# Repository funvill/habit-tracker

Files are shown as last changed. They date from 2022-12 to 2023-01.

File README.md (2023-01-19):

# Every DayCalendar - Single Month board - KiCad

A single month habit tracker inspired by [Simone Giertz “The Every Day Calendar”](https://www.kickstarter.com/projects/simonegiertz/the-every-day-calendar). Allows for tracking of stats for multiple activities throughout the year. On each day, click the buttons for the activities that you have accomplished and the corresponding date on the calendar will illuminate with RGB LEDs.

- Months will progress automatically.
- Several different "modes"
- Physical buttons with leads to be able to expand on the board out to a frame.
- Ability to connect the boards together

Uses a ESP32 to connect to the internet and backup the data from the boards.

Fabricated using JLPCB SMD placement services. Fully automated manufacturing.

More information about this project can be found on my blog [project page](https://blog.abluestar.com/projects/2022-monthly-habit-tracker/)

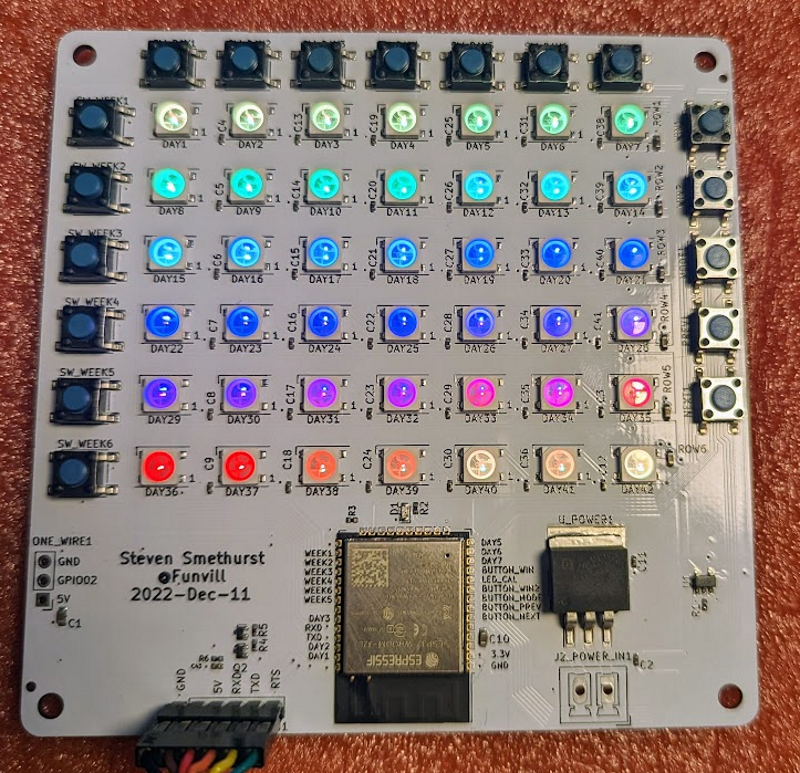
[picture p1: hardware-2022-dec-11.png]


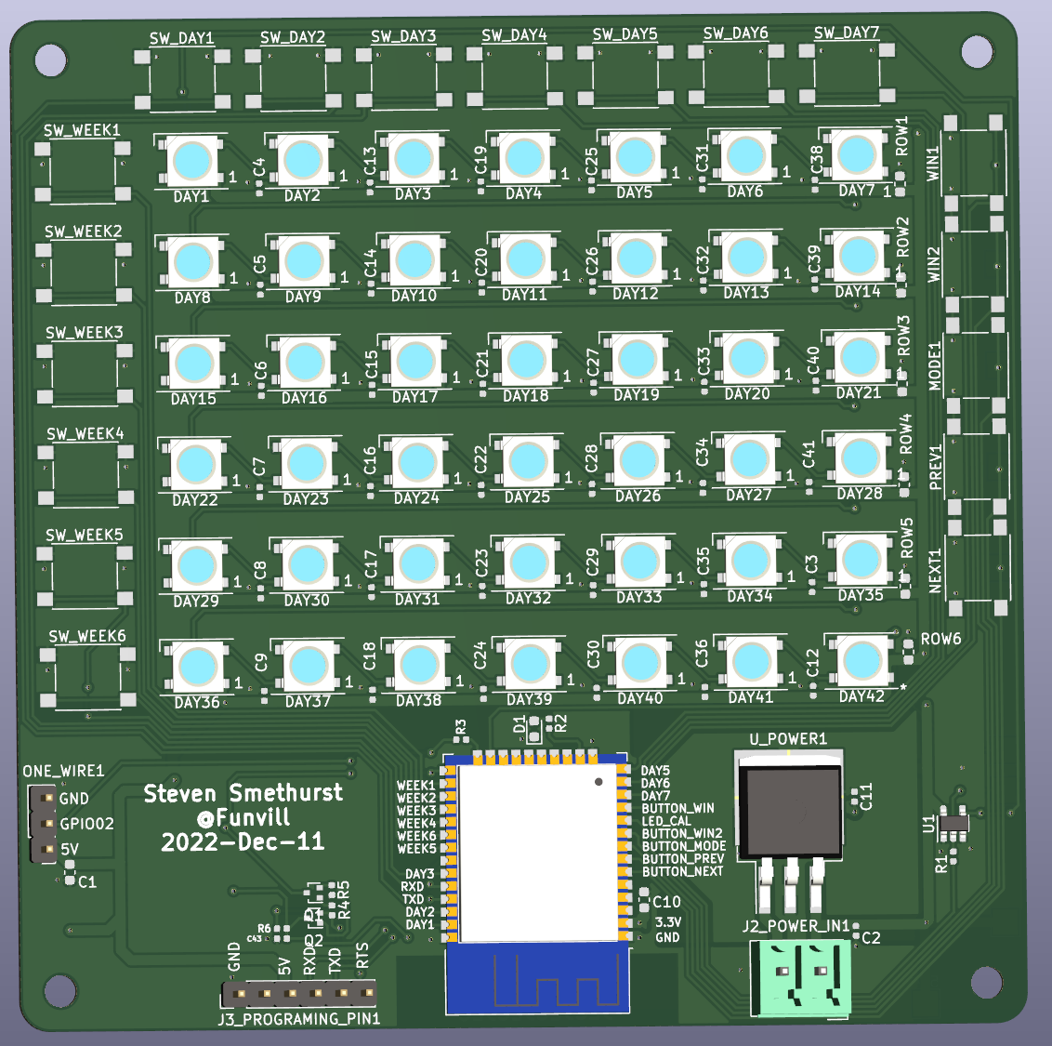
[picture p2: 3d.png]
3D


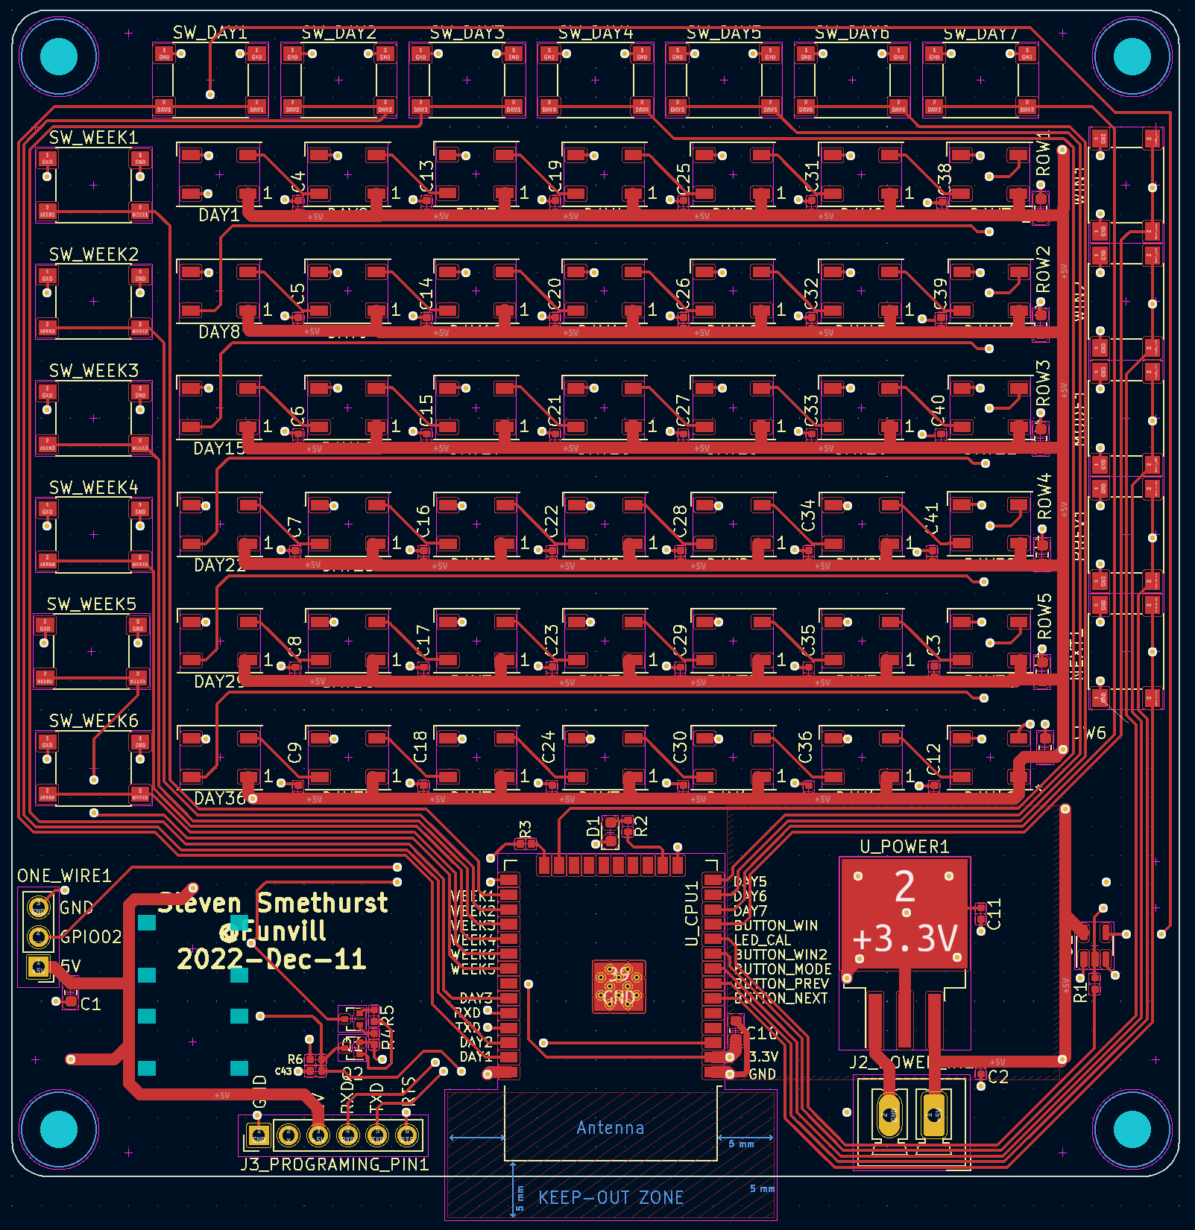
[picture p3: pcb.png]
PCB


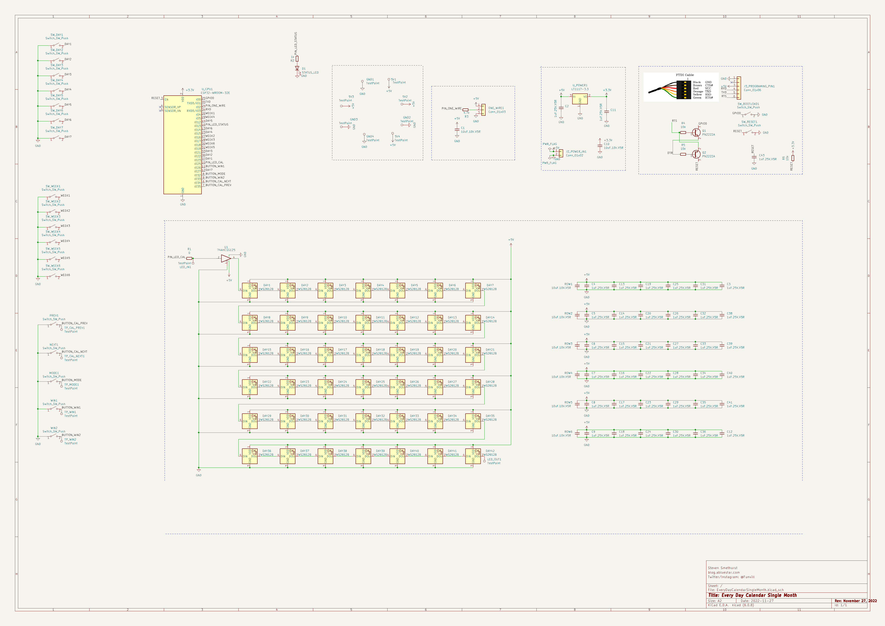
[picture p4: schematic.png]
Schematic


See [changelog](changelog.md) for full list of changes

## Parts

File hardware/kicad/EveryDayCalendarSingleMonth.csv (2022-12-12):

Comment | Designator | Footprint | LCSC
TestPoint | GND1,LED_IN1,LED_OUT1,TP_CAL_NEXT1,TP_CAL_PREV1,TP_MODE1,TP_WIN1,GND2,TP_WIN2,GND3,GND4,5V1,5V2,5V3,5V4 | TestPoint:TestPoint_Pad_2.5x2.5mm
10uF,10V,X5R | C1,ROW1,ROW2,ROW3,ROW4,ROW5,ROW6,C10 | tom-passives:C_0603_1608Metric | C19702
1uF,25V,X5R | C2,C3,C4,C5,C6,C7,C8,C9,C11,C12,C13,C14,C15,C16,C17,C18,C19,C20,C21,C22,C23,C24,C25,C26,C27,C28,C29,C30,C31,C32,C33,C34,C35,C36,C38,C39,C40,C41,C43 | tom-passives:C_0402_1005Metric | C52923
STATUS_LED | D1 | tom-opto:LED_0603_1608Metric | C2286
WS2812B | DAY1,DAY2,DAY3,DAY4,DAY5,DAY6,DAY7,DAY8,DAY9,DAY10,DAY11,DAY12,DAY13,DAY14,DAY15,DAY16,DAY17,DAY18,DAY19,DAY20,DAY21,DAY22,DAY23,DAY24,DAY25,DAY26,DAY27,DAY28,DAY29,DAY30,DAY31,DAY32,DAY33,DAY34,DAY35,DAY36,DAY37,DAY38,DAY39,DAY40,DAY41,DAY42 | LED_SMD:LED_WS2812B_PLCC4_5.0x5.0mm_P3.2mm | C2843785
Conn_01x02 | J2_POWER_IN1 | Connector_Phoenix_MC:PhoenixContact_MCV_1,5_2-G-3.81_1x02_P3.81mm_Vertical
Conn_01x06 | J3_PROGRAMING_PIN1 | Connector_PinHeader_2.54mm:PinHeader_1x06_P2.54mm_Vertical
Switch_SW_Push | MODE1,NEXT1,PREV1,SW_BOOTLOAD1,SW_DAY1,SW_RESET1,SW_WEEK1,WIN1,SW_DAY2,SW_WEEK2,WIN2,SW_DAY3,SW_WEEK3,SW_DAY4,SW_WEEK4,SW_DAY5,SW_WEEK5,SW_DAY6,SW_WEEK6,SW_DAY7 | calendar:SW_Push_1P1T_NO_6x6mm_H9.5mm | C221880
Conn_01x03 | ONE_WIRE1 | Connector_PinHeader_2.54mm:PinHeader_1x03_P2.54mm_Vertical
PN2222A | Q1,Q2 | Package_TO_SOT_SMD:SOT-416 | C242260
0 | R1 | tom-passives:R_0402_1005Metric | C17168
1k | R2 | tom-passives:R_0402_1005Metric | C11702
4.7k | R3 | tom-passives:R_0402_1005Metric | C25900
10k | R4,R5,R6 | tom-passives:R_0402_1005Metric | C25744
74AHC1G125 | U1 | calendar:SOT-23-5 | C23654
ESP32-WROOM-32E | U_CPU1 | RF_Module:ESP32-WROOM-32 | C701342
LT1117-3.3 | U_POWER1 | Package_TO_SOT_SMD:TO-263-3_TabPin2 | C498315

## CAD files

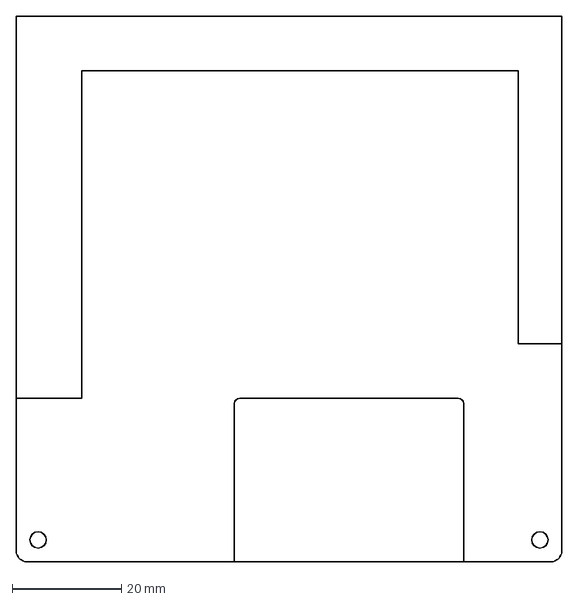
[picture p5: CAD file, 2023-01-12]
mounting/1month_top_plate.dxf
100.0 x 100.0 mm

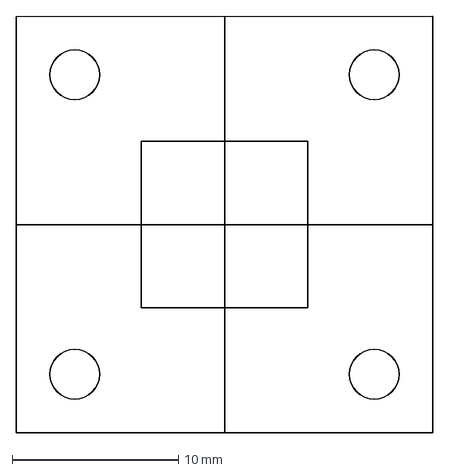
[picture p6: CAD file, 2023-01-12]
mounting/seperator.dxf
25.0 x 25.0 mm

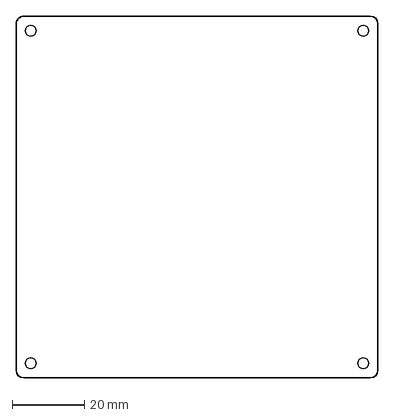
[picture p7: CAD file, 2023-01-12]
mounting/1month_bottom_plate.dxf
100.0 x 100.0 mm

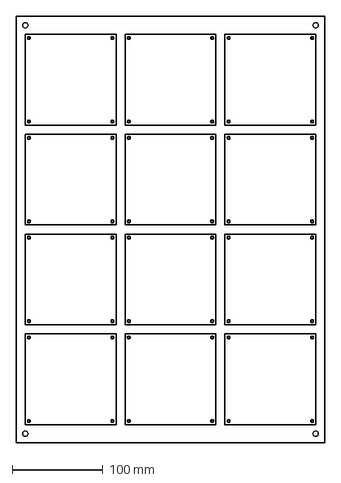
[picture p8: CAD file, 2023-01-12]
mounting/12MonthCalendar_backing.dxf
340.0 x 470.0 mm

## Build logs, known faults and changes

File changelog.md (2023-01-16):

# Change log

## 2023-Jan-08 (build 8)

- Fixed isssue where mode was not being saved between power cycles
## 2023-Jan-08 (build 7)

- Fixed bug where year was read from settings as a signed instead of unsigned short
- Removed github actions that are not needed

## 2023-Jan-08 (build 6)

- Save the month, year, and mode to eeprom on change
- Randomized seed on startup based on wifi noise

## 2023-Jan-08 (build 3-5)

- Added ability to update via Github

## 2023-Jan-03 (build 2)

- Added a fades pixel animation
- Moved modes to their own files
- Added reset wifi command

## 2022-Dec-29 (build 1)

- Intial version
- Added mode Calendar
  - Set current date objectives
  - Button to go to Next and Previouse month/year
  - Requires internet connection for NTP server (time)
- Captive portal on start up for entering Wifi settings
- Web server
  - Current state
  - Reset database
  - download database
- Reading/Writing to EEPROM
  - settings and database
- Added mode binary clock

## 2022-Dec-26

- Hardware recived

## 2022-Dec-11

- Hardware design done
- Submitted the PCBs to the fabrication servive (JLPCB) for manufacturing.

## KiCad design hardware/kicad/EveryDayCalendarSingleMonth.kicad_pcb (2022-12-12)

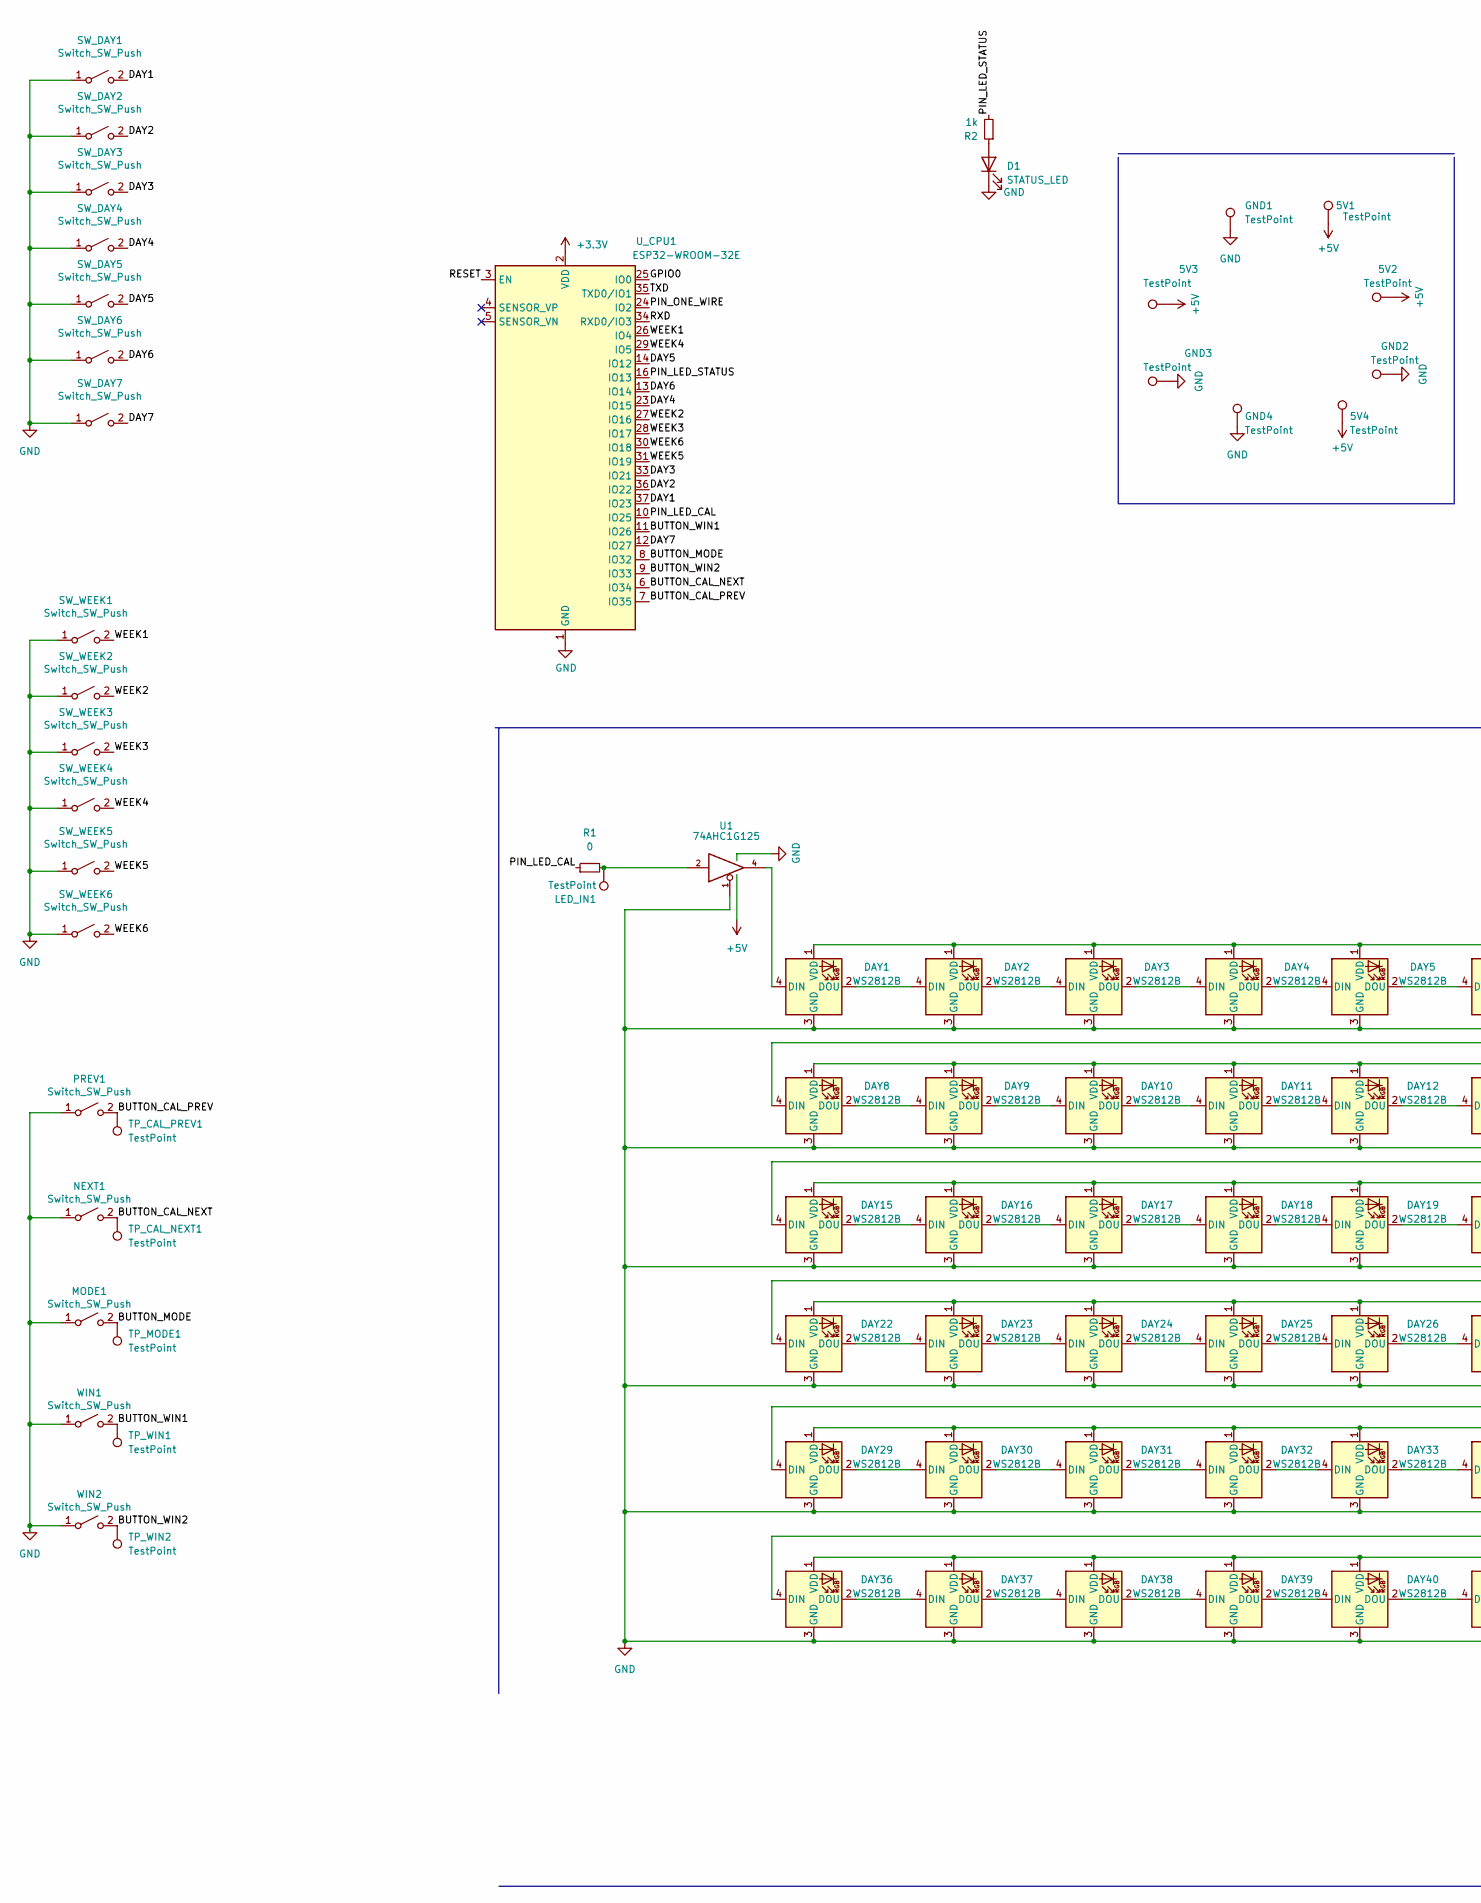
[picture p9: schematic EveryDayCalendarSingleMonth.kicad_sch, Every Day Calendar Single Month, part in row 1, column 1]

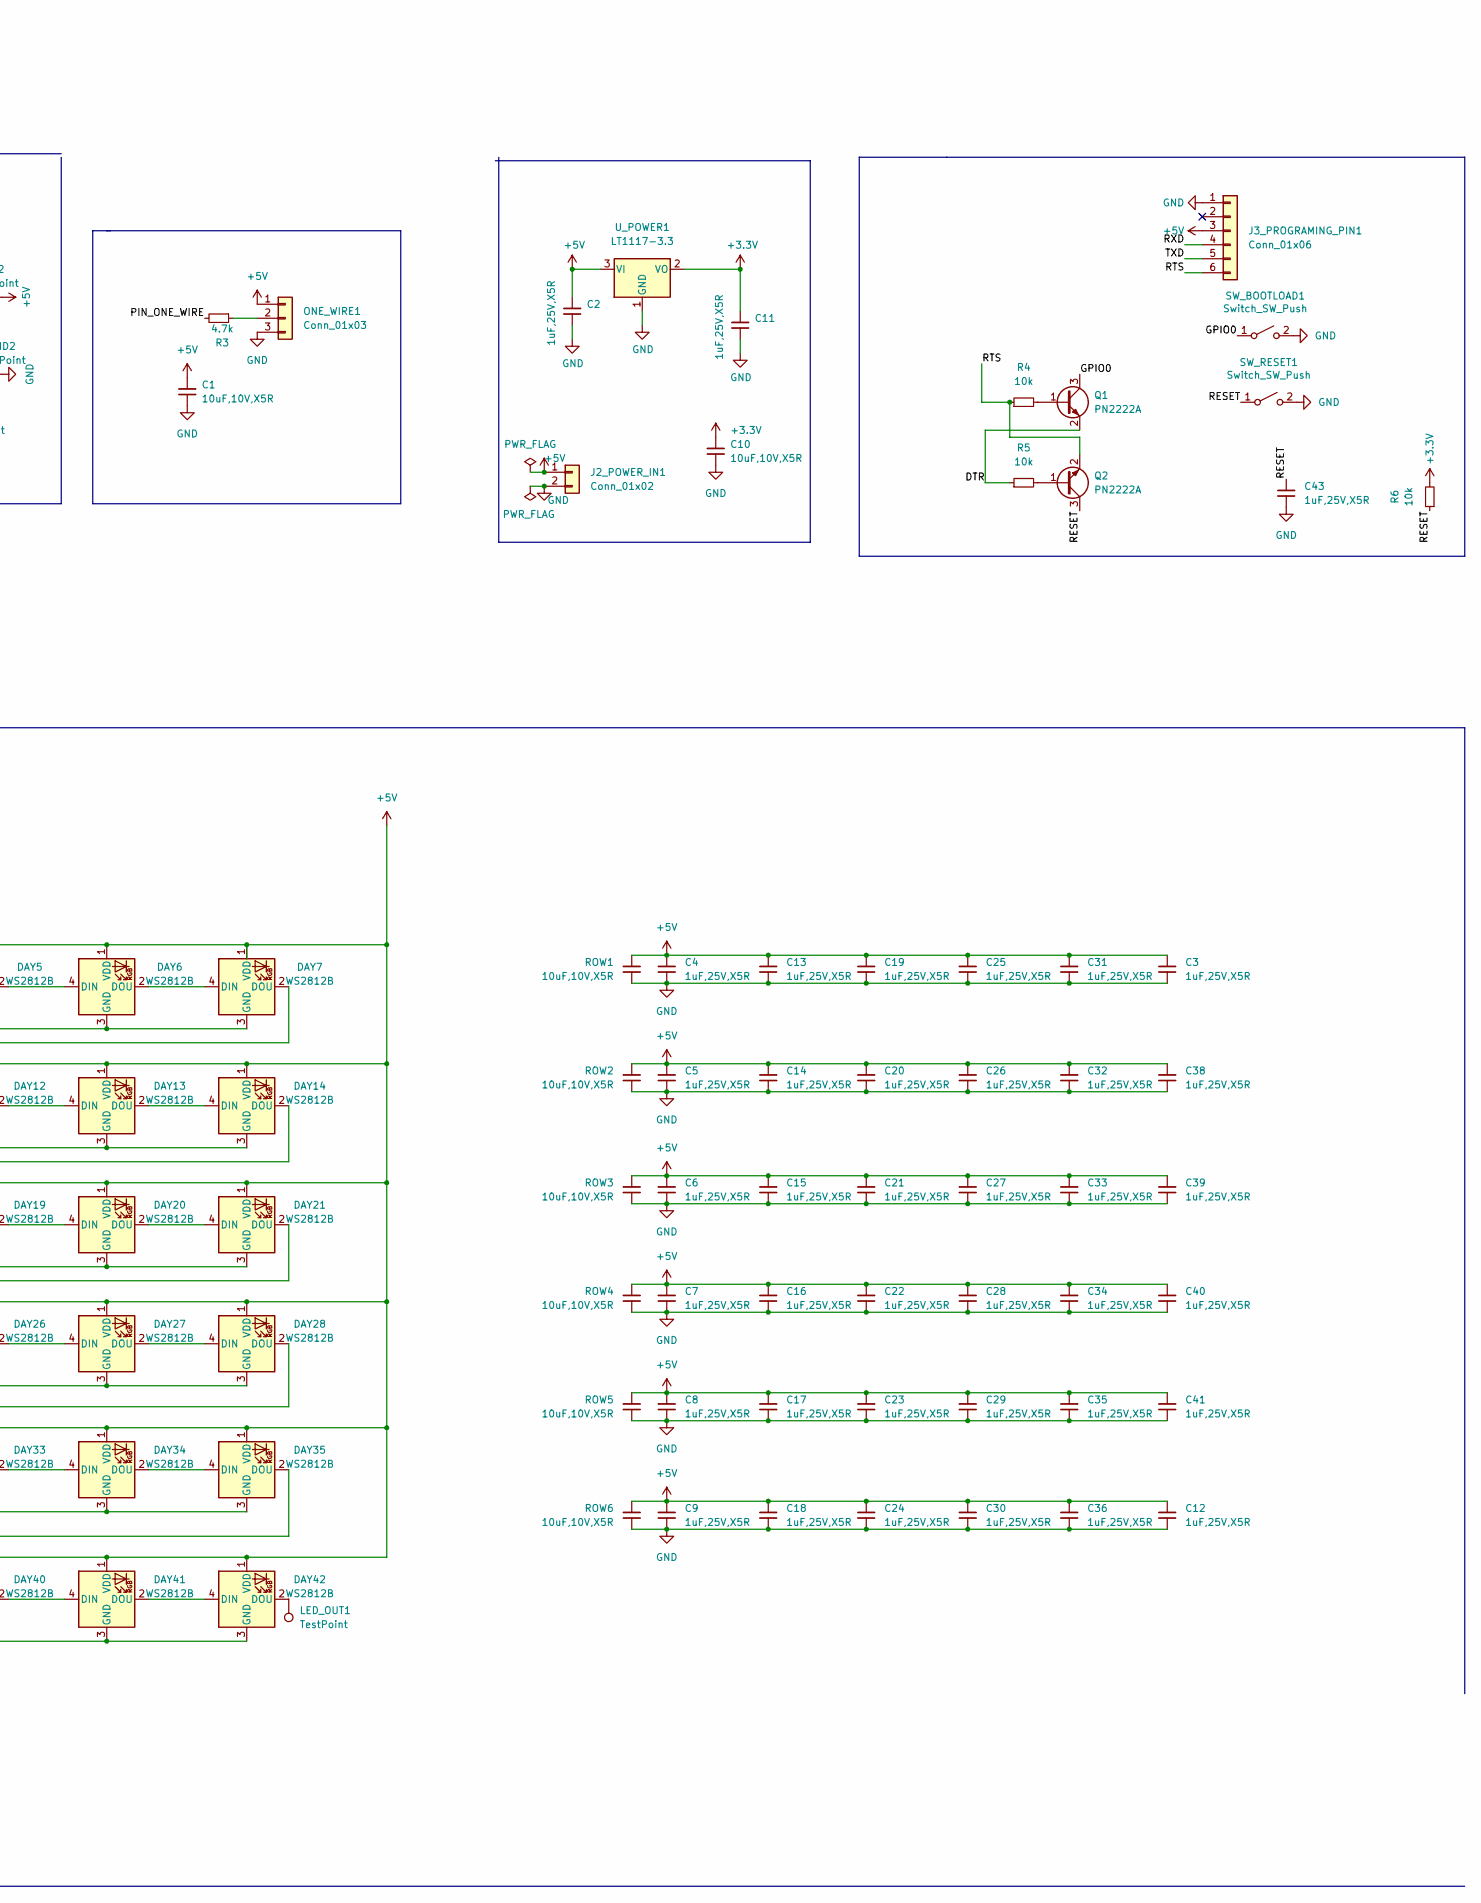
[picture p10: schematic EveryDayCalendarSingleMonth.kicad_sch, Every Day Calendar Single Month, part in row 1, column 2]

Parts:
5V1, 5V2, 5V3, 5V4: TestPoint; TestPoint_Pad_2.5x2.5mm
C1, C10: 10uF,10V,X5R; C_0603_1608Metric; MFGPN CL10A106KP8NNNC; LCSC C19702
C2, C3, C4, C5, C6, C7, C8, C9, C11, C12, C13, C14, C15, C16, C17, C18, C19, C20, C21, C22, C23, C24, C25, C26, C27, C28, C29, C30, C31, C32, C33, C34, C35, C36, C38, C39, C40, C41, C43: 1uF,25V,X5R; C_0402_1005Metric; MFGPN CL05A105KA5NQNC; LCSC C52923
D1: STATUS_LED; LED_0603_1608Metric; LCSC C2286
DAY1, DAY2, DAY3, DAY4, DAY5, DAY6, DAY7, DAY8, DAY9, DAY10, DAY11, DAY12, DAY13, DAY14, DAY15, DAY16, DAY17, DAY18, DAY19, DAY20, DAY21, DAY22, DAY23, DAY24, DAY25, DAY26, DAY27, DAY28, DAY29, DAY30, DAY31, DAY32, DAY33, DAY34, DAY35, DAY36, DAY37, DAY38, DAY39, DAY40, DAY41, DAY42: WS2812B; LED_WS2812B_PLCC4_5.0x5.0mm_P3.2mm; LCSC C2843785
GND1, GND2, GND3, GND4: TestPoint; TestPoint_Pad_2.5x2.5mm
J2_POWER_IN1: Conn_01x02; PhoenixContact_MCV_1,5_2-G-3.81_1x02_P3.81mm_Vertical
J3_PROGRAMING_PIN1: Conn_01x06; PinHeader_1x06_P2.54mm_Vertical
LED_IN1: TestPoint; TestPoint_Pad_2.5x2.5mm
LED_OUT1: TestPoint; TestPoint_Pad_2.5x2.5mm
MODE1: Switch_SW_Push; SW_Push_1P1T_NO_6x6mm_H9.5mm; LCSC C221880
NEXT1: Switch_SW_Push; SW_Push_1P1T_NO_6x6mm_H9.5mm; LCSC C221880
ONE_WIRE1: Conn_01x03; PinHeader_1x03_P2.54mm_Vertical
PREV1: Switch_SW_Push; SW_Push_1P1T_NO_6x6mm_H9.5mm; LCSC C221880
Q1, Q2: PN2222A; SOT-416; LCSC C242260
R1: 0; R_0402_1005Metric; MFGPN 0402WGF0000TCE; LCSC C17168
R2: 1k; R_0402_1005Metric; MFGPN 0402WGF1001TCE; LCSC C11702
R3: 4.7k; R_0402_1005Metric; MFGPN 0402WGF4701TCE; LCSC C25900
R4, R5, R6: 10k; R_0402_1005Metric; MFGPN 0402WGF1002TCE; LCSC C25744
ROW1, ROW2, ROW3, ROW4, ROW5, ROW6: 10uF,10V,X5R; C_0603_1608Metric; MFGPN CL10A106KP8NNNC; LCSC C19702
SW_BOOTLOAD1: Switch_SW_Push; SW_Push_1P1T_NO_6x6mm_H9.5mm; LCSC DNP
SW_DAY1, SW_DAY2, SW_DAY3, SW_DAY4, SW_DAY5, SW_DAY6, SW_DAY7: Switch_SW_Push; SW_Push_1P1T_NO_6x6mm_H9.5mm; LCSC C221880
SW_RESET1: Switch_SW_Push; SW_Push_1P1T_NO_6x6mm_H9.5mm; LCSC DNP
SW_WEEK1, SW_WEEK2, SW_WEEK3, SW_WEEK4, SW_WEEK5, SW_WEEK6: Switch_SW_Push; SW_Push_1P1T_NO_6x6mm_H9.5mm; LCSC C221880
TP_CAL_NEXT1: TestPoint; TestPoint_Pad_2.5x2.5mm
TP_CAL_PREV1: TestPoint; TestPoint_Pad_2.5x2.5mm
TP_MODE1: TestPoint; TestPoint_Pad_2.5x2.5mm
TP_WIN1, TP_WIN2: TestPoint; TestPoint_Pad_2.5x2.5mm
U1: 74AHC1G125; SOT-23-5; LCSC C23654
U_CPU1: ESP32-WROOM-32E; ESP32-WROOM-32; LCSC C701342
U_POWER1: LT1117-3.3; TO-263-3_TabPin2; LCSC C498315
WIN1, WIN2: Switch_SW_Push; SW_Push_1P1T_NO_6x6mm_H9.5mm; LCSC C221880

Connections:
+3.3V: C10.1, C11.1, R6.2, U_CPU1.2 (VDD), U_POWER1.2 (VO)
+5V: 5V1.1, 5V2.1, 5V3.1, 5V4.1, C1.1, C2.1, C3.1, C4.1, C5.1, C6.1, C7.1, C8.1, C9.1, C12.1, C13.1, C14.1, C15.1, C16.1, C17.1, C18.1, C19.1, C20.1, C21.1, C22.1, C23.1, C24.1, C25.1, C26.1, C27.1, C28.1, C29.1, C30.1, C31.1, C32.1, C33.1, C34.1, C35.1, C36.1, C38.1, C39.1, C40.1, C41.1, DAY1.1 (VDD), DAY2.1 (VDD), DAY3.1 (VDD), DAY4.1 (VDD), DAY5.1 (VDD), DAY6.1 (VDD), DAY7.1 (VDD), DAY8.1 (VDD), DAY9.1 (VDD), DAY10.1 (VDD), DAY11.1 (VDD), DAY12.1 (VDD), DAY13.1 (VDD), DAY14.1 (VDD), DAY15.1 (VDD), DAY16.1 (VDD), DAY17.1 (VDD), DAY18.1 (VDD), DAY19.1 (VDD), DAY20.1 (VDD), DAY21.1 (VDD), DAY22.1 (VDD), DAY23.1 (VDD), DAY24.1 (VDD), DAY25.1 (VDD), DAY26.1 (VDD), DAY27.1 (VDD), DAY28.1 (VDD), DAY29.1 (VDD), DAY30.1 (VDD), DAY31.1 (VDD), DAY32.1 (VDD), DAY33.1 (VDD), DAY34.1 (VDD), DAY35.1 (VDD), DAY36.1 (VDD), DAY37.1 (VDD), DAY38.1 (VDD), DAY39.1 (VDD), DAY40.1 (VDD), DAY41.1 (VDD), DAY42.1 (VDD), J2_POWER_IN1.1, J3_PROGRAMING_PIN1.3, ONE_WIRE1.1, ROW1.2, ROW2.2, ROW3.2, ROW4.2, ROW5.2, ROW6.2, U1.5 (VCC), U_POWER1.3 (VI)
/BUTTON_CAL_NEXT: NEXT1.2 (B), TP_CAL_NEXT1.1, U_CPU1.6 (IO34)
/BUTTON_CAL_PREV: PREV1.2 (B), TP_CAL_PREV1.1, U_CPU1.7 (IO35)
/BUTTON_MODE: MODE1.2 (B), TP_MODE1.1, U_CPU1.8 (IO32)
/BUTTON_WIN1: TP_WIN1.1, U_CPU1.11 (IO26), WIN1.2 (B)
/BUTTON_WIN2: TP_WIN2.1, U_CPU1.9 (IO33), WIN2.2 (B)
/DAY1: SW_DAY1.2 (B), U_CPU1.37 (IO23)
/DAY2: SW_DAY2.2 (B), U_CPU1.36 (IO22)
/DAY3: SW_DAY3.2 (B), U_CPU1.33 (IO21)
/DAY4: SW_DAY4.2 (B), U_CPU1.23 (IO15)
/DAY5: SW_DAY5.2 (B), U_CPU1.14 (IO12)
/DAY6: SW_DAY6.2 (B), U_CPU1.13 (IO14)
/DAY7: SW_DAY7.2 (B), U_CPU1.12 (IO27)
/DTR: Q1.2 (E), R5.1
/GPIO0: Q1.3 (C), SW_BOOTLOAD1.1 (A), U_CPU1.25 (IO0)
/PIN_LED_CAL: R1.1, U_CPU1.10 (IO25)
/PIN_LED_STATUS: R2.2, U_CPU1.16 (IO13)
/PIN_ONE_WIRE: R3.2, U_CPU1.24 (IO2)
/RESET: C43.1, Q2.3 (C), R6.1, SW_RESET1.1 (A), U_CPU1.3 (EN)
/RTS: J3_PROGRAMING_PIN1.6, Q2.2 (E), R4.1
/RXD: J3_PROGRAMING_PIN1.4, U_CPU1.34 (RXD0/IO3)
/TXD: J3_PROGRAMING_PIN1.5, U_CPU1.35 (TXD0/IO1)
/WEEK1: SW_WEEK1.2 (B), U_CPU1.26 (IO4)
/WEEK2: SW_WEEK2.2 (B), U_CPU1.27 (IO16)
/WEEK3: SW_WEEK3.2 (B), U_CPU1.28 (IO17)
/WEEK4: SW_WEEK4.2 (B), U_CPU1.29 (IO5)
/WEEK5: SW_WEEK5.2 (B), U_CPU1.31 (IO19)
/WEEK6: SW_WEEK6.2 (B), U_CPU1.30 (IO18)
GND: C1.2, C2.2, C3.2, C4.2, C5.2, C6.2, C7.2, C8.2, C9.2, C10.2, C11.2, C12.2, C13.2, C14.2, C15.2, C16.2, C17.2, C18.2, C19.2, C20.2, C21.2, C22.2, C23.2, C24.2, C25.2, C26.2, C27.2, C28.2, C29.2, C30.2, C31.2, C32.2, C33.2, C34.2, C35.2, C36.2, C38.2, C39.2, C40.2, C41.2, C43.2, D1.1 (K), DAY1.3 (GND), DAY2.3 (GND), DAY3.3 (GND), DAY4.3 (GND), DAY5.3 (GND), DAY6.3 (GND), DAY7.3 (GND), DAY8.3 (GND), DAY9.3 (GND), DAY10.3 (GND), DAY11.3 (GND), DAY12.3 (GND), DAY13.3 (GND), DAY14.3 (GND), DAY15.3 (GND), DAY16.3 (GND), DAY17.3 (GND), DAY18.3 (GND), DAY19.3 (GND), DAY20.3 (GND), DAY21.3 (GND), DAY22.3 (GND), DAY23.3 (GND), DAY24.3 (GND), DAY25.3 (GND), DAY26.3 (GND), DAY27.3 (GND), DAY28.3 (GND), DAY29.3 (GND), DAY30.3 (GND), DAY31.3 (GND), DAY32.3 (GND), DAY33.3 (GND), DAY34.3 (GND), DAY35.3 (GND), DAY36.3 (GND), DAY37.3 (GND), DAY38.3 (GND), DAY39.3 (GND), DAY40.3 (GND), DAY41.3 (GND), DAY42.3 (GND), GND1.1, GND2.1, GND3.1, GND4.1, J2_POWER_IN1.2, J3_PROGRAMING_PIN1.1, MODE1.1 (A), NEXT1.1 (A), ONE_WIRE1.3, PREV1.1 (A), ROW1.1, ROW2.1, ROW3.1, ROW4.1, ROW5.1, ROW6.1, SW_BOOTLOAD1.2 (B), SW_DAY1.1 (A), SW_DAY2.1 (A), SW_DAY3.1 (A), SW_DAY4.1 (A), SW_DAY5.1 (A), SW_DAY6.1 (A), SW_DAY7.1 (A), SW_RESET1.2 (B), SW_WEEK1.1 (A), SW_WEEK2.1 (A), SW_WEEK3.1 (A), SW_WEEK4.1 (A), SW_WEEK5.1 (A), SW_WEEK6.1 (A), U1.1, U1.3 (GND), U_CPU1.1 (GND), U_CPU1.15 (GND), U_CPU1.38 (GND), U_CPU1.39 (GND), U_POWER1.1 (GND), WIN1.1 (A), WIN2.1 (A)
unnamed: D1.2 (A), R2.1
unnamed: DAY1.2 (DOU), DAY2.4 (DIN)
unnamed: DAY1.4 (DIN), U1.4
unnamed: DAY2.2 (DOU), DAY3.4 (DIN)
unnamed: DAY3.2 (DOU), DAY4.4 (DIN)
unnamed: DAY4.2 (DOU), DAY5.4 (DIN)
unnamed: DAY5.2 (DOU), DAY6.4 (DIN)
unnamed: DAY6.2 (DOU), DAY7.4 (DIN)
unnamed: DAY7.2 (DOU), DAY8.4 (DIN)
unnamed: DAY8.2 (DOU), DAY9.4 (DIN)
unnamed: DAY10.2 (DOU), DAY11.4 (DIN)
unnamed: DAY9.2 (DOU), DAY10.4 (DIN)
unnamed: DAY11.2 (DOU), DAY12.4 (DIN)
unnamed: DAY12.2 (DOU), DAY13.4 (DIN)
unnamed: DAY13.2 (DOU), DAY14.4 (DIN)
unnamed: DAY14.2 (DOU), DAY15.4 (DIN)
unnamed: DAY15.2 (DOU), DAY16.4 (DIN)
unnamed: DAY16.2 (DOU), DAY17.4 (DIN)
unnamed: DAY17.2 (DOU), DAY18.4 (DIN)
unnamed: DAY18.2 (DOU), DAY19.4 (DIN)
unnamed: DAY19.2 (DOU), DAY20.4 (DIN)
unnamed: DAY20.2 (DOU), DAY21.4 (DIN)
unnamed: DAY21.2 (DOU), DAY22.4 (DIN)
unnamed: DAY22.2 (DOU), DAY23.4 (DIN)
unnamed: DAY23.2 (DOU), DAY24.4 (DIN)
unnamed: DAY24.2 (DOU), DAY25.4 (DIN)
unnamed: DAY25.2 (DOU), DAY26.4 (DIN)
unnamed: DAY26.2 (DOU), DAY27.4 (DIN)
unnamed: DAY27.2 (DOU), DAY28.4 (DIN)
unnamed: DAY28.2 (DOU), DAY29.4 (DIN)
unnamed: DAY29.2 (DOU), DAY30.4 (DIN)
unnamed: DAY30.2 (DOU), DAY31.4 (DIN)
unnamed: DAY31.2 (DOU), DAY32.4 (DIN)
unnamed: DAY32.2 (DOU), DAY33.4 (DIN)
unnamed: DAY33.2 (DOU), DAY34.4 (DIN)
unnamed: DAY34.2 (DOU), DAY35.4 (DIN)
unnamed: DAY35.2 (DOU), DAY36.4 (DIN)
unnamed: DAY36.2 (DOU), DAY37.4 (DIN)
unnamed: DAY37.2 (DOU), DAY38.4 (DIN)
unnamed: DAY38.2 (DOU), DAY39.4 (DIN)
unnamed: DAY39.2 (DOU), DAY40.4 (DIN)
unnamed: DAY40.2 (DOU), DAY41.4 (DIN)
unnamed: DAY41.2 (DOU), DAY42.4 (DIN)
unnamed: DAY42.2 (DOU), LED_OUT1.1
unnamed: LED_IN1.1, R1.2, U1.2
unnamed: ONE_WIRE1.2, R3.1
unnamed: Q1.1 (B), R4.2
unnamed: Q2.1 (B), R5.2

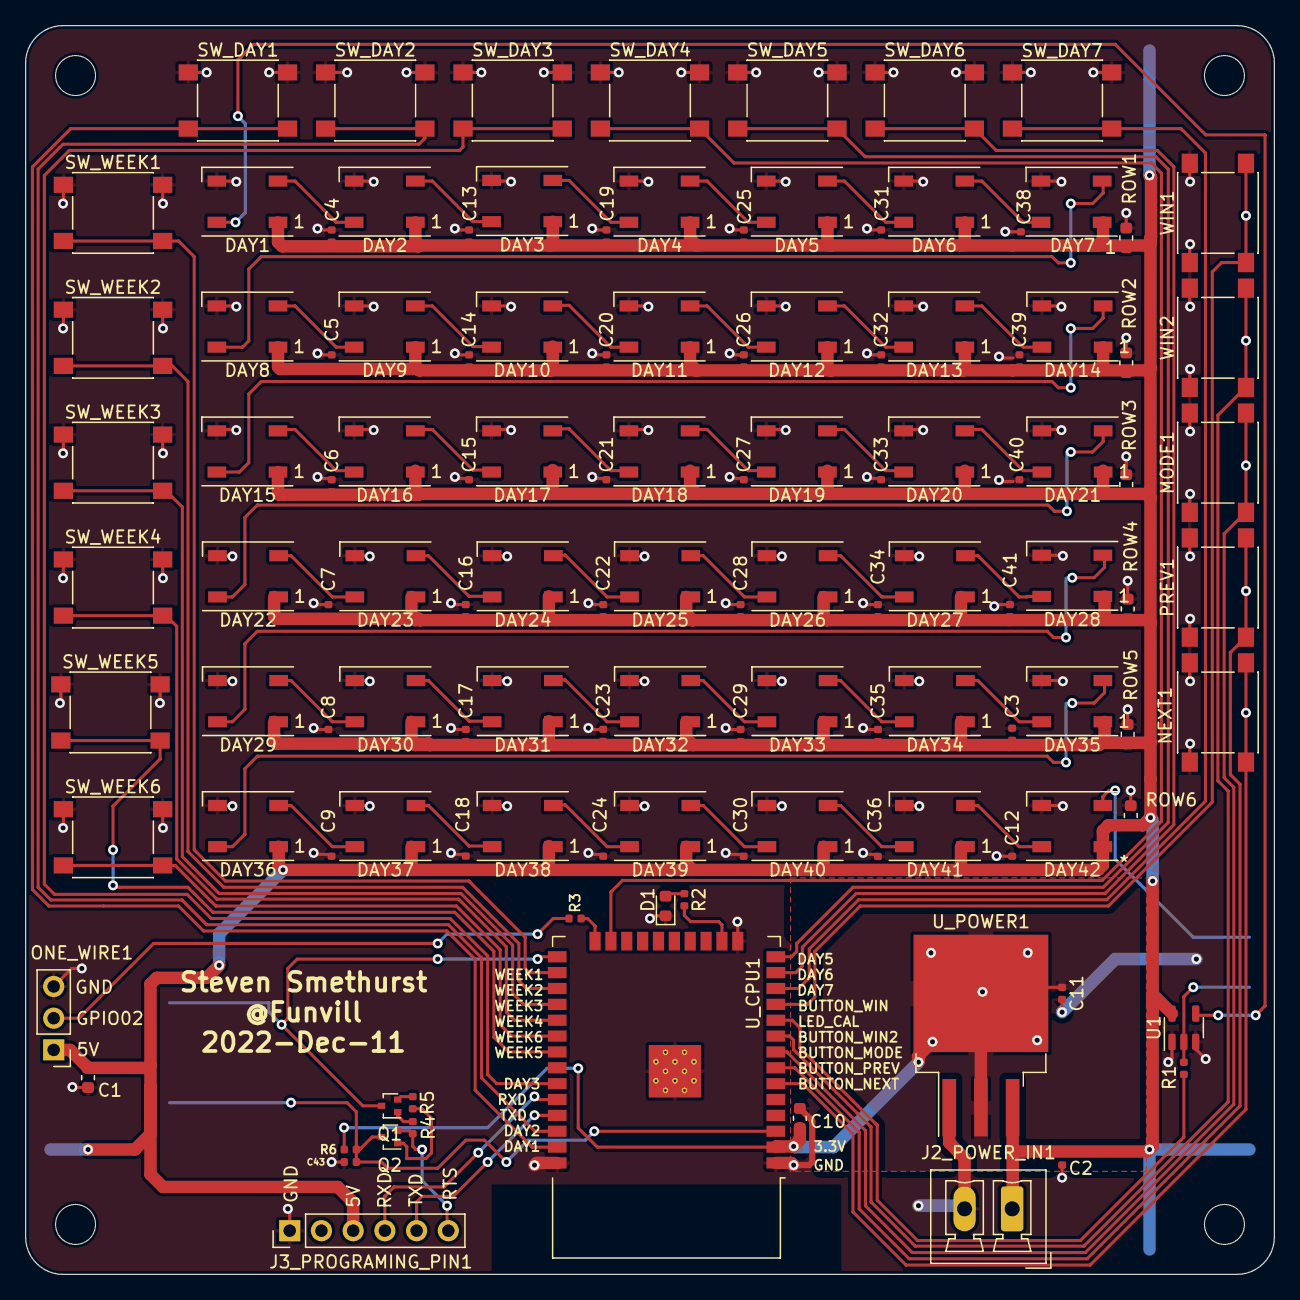
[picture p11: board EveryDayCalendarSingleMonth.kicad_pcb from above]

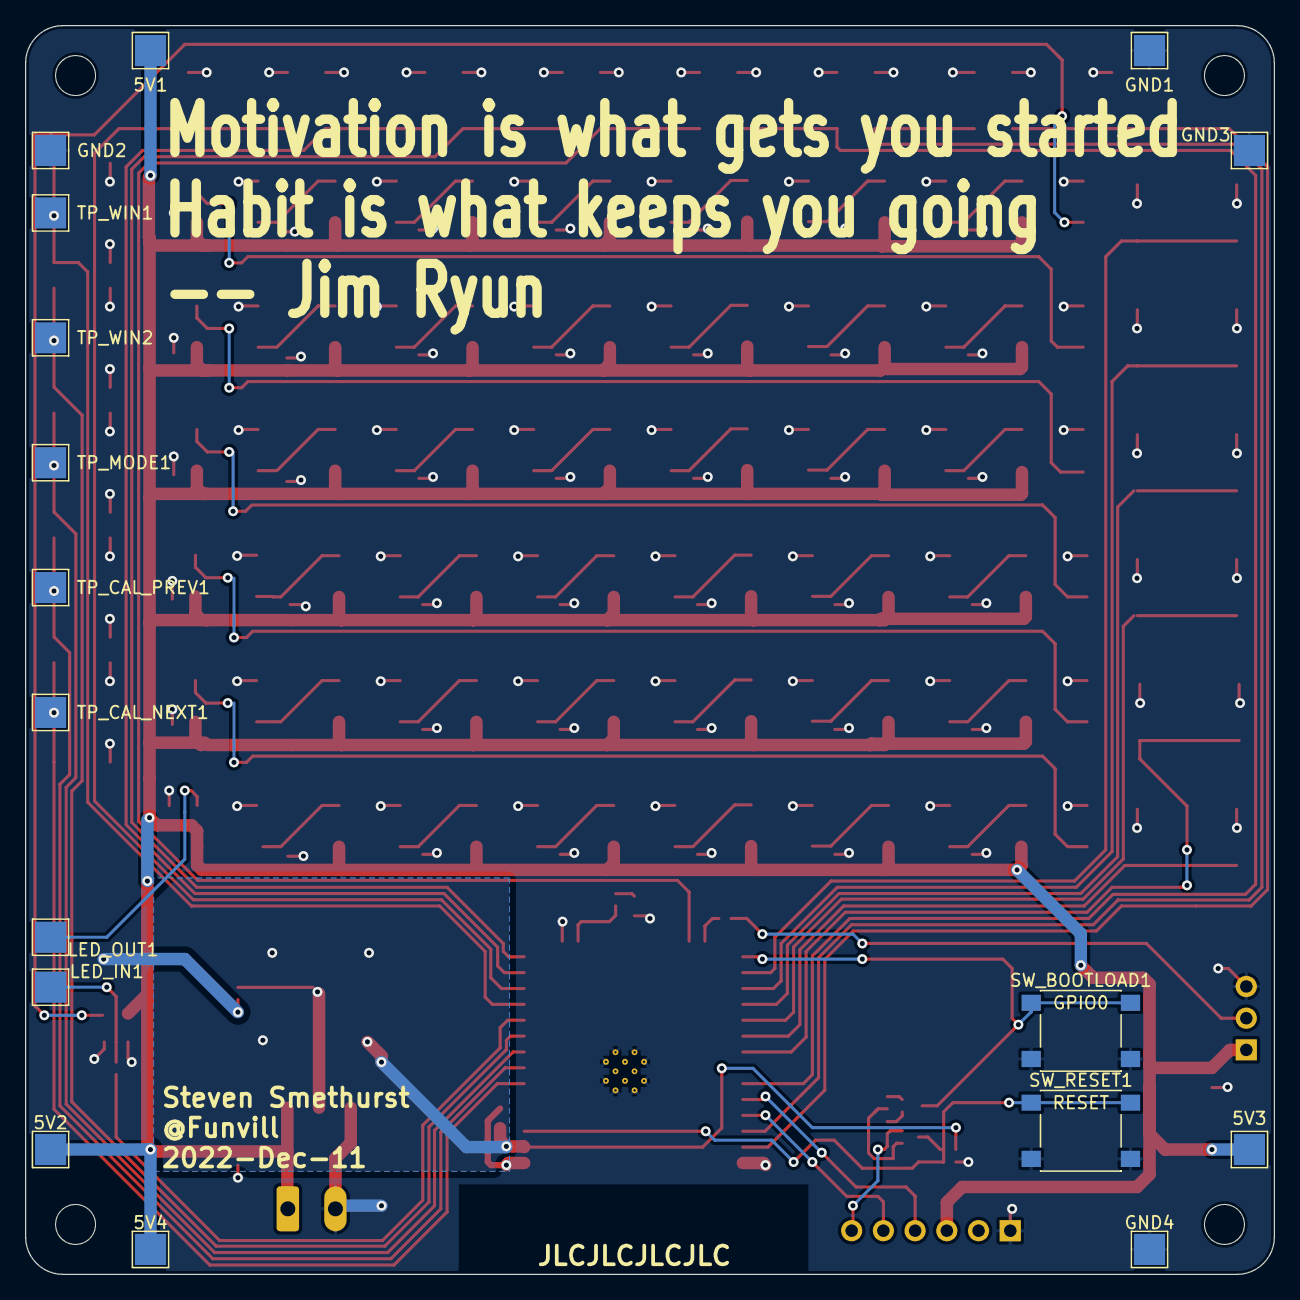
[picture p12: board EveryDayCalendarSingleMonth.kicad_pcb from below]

Board: 2 copper layers, 100.0 x 100.0 mm, 143 parts (17 on the bottom side), 78 nets.

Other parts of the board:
TP_CORNER_1, TP_CORNER_2, TP_CORNER_3, TP_CORNER_4: TestPoint; MountingHole_3.2mm_M3

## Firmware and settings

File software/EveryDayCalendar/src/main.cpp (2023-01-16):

/**
 * EveryDayCalendar
 *
 *
 * ToDo:
 * MVP
 * [x] Database and settings download from web page
 * - Update previouse day in the database. (cursor)
 * [x] Once connected print the IP address to the matrix
 *
 * Nice to have
 * - Synch database to online store
 * - Symbols for each mode instead of text.
 * - Update settings from web page
 *   - Timezone, UTC offset, NTP server, LED brightness, etc.
 *   - Colors
 */
#include <Arduino.h>
#include "FastLED.h"
#include <WiFi.h>

#include <time.h>
#include <TimeLib.h>
#include <NTPClient.h>
#include <WiFiUdp.h>
#include <DNSServer.h> // DNS server used for captive portal

#include "EEPROM.h"

#include "globals.h"
#include "font.h"
#include "database.h"
#include "animation.h"
#include "http.h"

// Modes
#include "modes/fadepoints.h"
#include "modes/clocks.h"

CRGB leds[PIXELS_COUNT];

const char *NTP_SERVER = "pool.ntp.org";

// Automatic updates
#include <esp32FOTA.hpp>
esp32FOTA esp32FOTA("esp32-habit-tracker", BUILD_NUMBER, false, true);
const char *manifest_url = "https://blog.abluestar.com/habit-tracker/firmware.json";
//

WiFiUDP ntpUDP;
NTPClient timeClient(ntpUDP, NTP_SERVER, utcOffsetInSeconds);

void flipTheStatusLED();
void checkInputs();
void getCurrentTime();
time_t getNtpTime();
void CheckForUpdates();

// Modes
void modeCalendar();
void modeClock();
void modeProgress();
void modeBreathing();

time_t GetEpochForDate(uint16_t year, uint8_t month, uint8_t day)
{
  tmElements_t tmSet;
  tmSet.Year = year - 1970; // tmElements_t year is offset from 1970
  tmSet.Month = month;      // Jan = 0
  tmSet.Day = day;          // 1st = 0
  tmSet.Hour = 0;
  tmSet.Minute = 0;
  tmSet.Second = 1;
  return makeTime(tmSet);
}

#include <WiFi.h>
#include <ESPConnect.h>
#include <AsyncTCP.h>
#include "ESPAsyncWebServer.h" // Used for displaying webpages
#include <AsyncElegantOTA.h>   // Used for Update via webpage. https://github.com/ayushsharma82/AsyncElegantOTA

// Set up the web server.
AsyncWebServer webServer(HTTP_PORT);
DNSServer dnsServer;

void setupServer()
{
  webServer.on("/", HTTP_GET, httpIndex);
  webServer.on("/database", HTTP_GET, httpDatabase);
  webServer.on("/set", HTTP_POST, httpSet);
  webServer.on("/reset", HTTP_GET, httpReset);
  webServer.on("/resetwifi", HTTP_GET, httpResetWifi);
}

void setup()
{
  // Set the status led to an output
  // This shows that there is power to the boards
  pinMode(PIN_LED_STATUS, OUTPUT);
  digitalWrite(PIN_LED_STATUS, HIGH);

  // Configure the LEDs
  FastLED.addLeds<NEOPIXEL, PIN_LED_CALENDAR>(leds, PIXELS_COUNT);
  // set master brightness control
  FastLED.setBrightness(LED_BRIGHTNESS);

  // Set all the buttons to inputs
  pinMode(PIN_WEEK1, INPUT_PULLUP);
  pinMode(PIN_WEEK2, INPUT_PULLUP);
  pinMode(PIN_WEEK3, INPUT_PULLUP);
  pinMode(PIN_WEEK4, INPUT_PULLUP);
  pinMode(PIN_WEEK5, INPUT_PULLUP);
  pinMode(PIN_WEEK6, INPUT_PULLUP);
  pinMode(PIN_DAY1, INPUT_PULLUP);
  pinMode(PIN_DAY2, INPUT_PULLUP);
  pinMode(PIN_DAY3, INPUT_PULLUP);
  pinMode(PIN_DAY4, INPUT_PULLUP);
  pinMode(PIN_DAY5, INPUT_PULLUP);
  pinMode(PIN_DAY6, INPUT_PULLUP);
  pinMode(PIN_DAY7, INPUT_PULLUP);
  pinMode(PIN_WIN1, INPUT_PULLUP);
  pinMode(PIN_WIN2, INPUT_PULLUP);
  pinMode(PIN_MODE, INPUT_PULLUP);

  // If Serial is active you can't use these pins
  // pinMode(PIN_PREV, INPUT_PULLUP);
  // pinMode(PIN_NEXT, INPUT_PULLUP);

  // Set up the serial port for debugging
  // this prevents the button_next, and button_prev from working
  Serial.begin(BAUD_RATE);

  // Wait for the serial port to be ready before continuing
  // We want to display the loading animation for at least 1 second
  // If the serial port fails to load, only wait up to 3 seconds.
  while ((!Serial && millis() < 1000 * 3) || millis() < 1000 * 1)
  {
    loadingAnimation();
    delay(1);
  }
  Serial.println("\n\n\n");

  // Print a message to the serial port
  Serial.println("EveryDayCalendar v" + String(BUILD_NUMBER));

  // Load the settings
  loadsDatabase();

  // Hardcode the SSID and password for intial loading of the firmware.
  Preferences preferences;
  // preferences.begin("espconnect", false);
  // if (preferences.isKey("ssid") == PT_INVALID)
  // {
  //   Serial.println("Using default SSID");
  //   preferences.putString("ssid", "DEFAULT-SSID");
  //   preferences.putString("password", "DEFAULT-PASSWORD");
  // }
  // preferences.end();
  preferences.begin("habit-tracker", false);
  if (preferences.isKey("mode") == PT_INVALID)
  {
    Serial.println("Using default Mode, Month, and Year");
    preferences.putUChar("mode", MODE_CALENDAR);
    preferences.putUChar("month", 1);
    preferences.putUShort("year", 2023);
  }
  preferences.end();

  // WifiManager
  ShowGlyphSearchingWiFi();
  String APSSID = (String) "EveryDayCalendar-" + WiFi.macAddress();
  ESPConnect.autoConnect(APSSID.c_str());
  if (ESPConnect.begin(&webServer))
  {
    Serial.println("Connected to WiFi");
    Serial.println("IPAddress: " + WiFi.localIP().toString());
    delay(100); // Give the TCP stack a chance to connect to the network
  }
  else
  {
    Serial.println("Failed to connect to WiFi");
    while (true)
    {
      animationNoWifi();
    }
    return;
  }

  // Start the DNS server
  dnsServer.start(53, "*", WiFi.softAPIP());

  // Configure the web server endpoints.
  AsyncElegantOTA.begin(&webServer); // Start AsyncElegantOTA
  setupServer();
  webServer.begin();

  Serial.println("\nConnected to the WiFi network");
  Serial.print("Network information for ");
  Serial.println(WiFi.SSID());

  Serial.println("BSSID : " + WiFi.BSSIDstr());
  Serial.print("MAC Address : ");
  Serial.println(WiFi.macAddress());
  Serial.print("Gateway IP : ");
  Serial.println(WiFi.gatewayIP());
  Serial.print("Subnet Mask : ");
  Serial.println(WiFi.subnetMask());
  Serial.println((String) "RSSI : " + WiFi.RSSI() + " dB");
  Serial.print("ESP32 IP : ");
  Serial.println(WiFi.localIP());

  // Print the IP address to the LEDS
  // ScrollText((String) "IP " + WiFi.localIP().toString());

  // Time server
  Serial.print("Connecting to time server NTP: ");
  Serial.println(NTP_SERVER);
  timeClient.begin();
  getNtpTime(); // Get the current time from the NTP server

  // Set the time to the current time from the NTP server
  setSyncProvider(getNtpTime);
  setSyncInterval(3600);

  // Print the time status
  getCurrentTime();
  printDatabase(year()); // Debug

  // Generate a random seed
  // https://docs.espressif.com/projects/esp-idf/en/latest/esp32/api-reference/system/random.html
  randomSeed(esp_random());
  Serial.println("Random number: " + String(random(1000)));

  // Load settings
  preferences.begin("habit-tracker", true);
  gMode = preferences.getUChar("mode", MODE_START);
  gCurrentMonth = preferences.getUChar("month", year());
  gCurrentYear = preferences.getUShort("year", month());
  preferences.end();

  if (gCurrentYear < 2020)
  {
    // There was an error somewhere. We need to reset the year to 2023
    Serial.println("Error: gCurrentYear < 2020 (was: " + String(gCurrentYear) + "). Resetting to 2023");
    gCurrentMonth = 1;
    gCurrentYear = 2023;

    preferences.begin("habit-tracker", false);
    preferences.putUShort("month", gCurrentMonth);
    preferences.putUShort("year", gCurrentYear);
    preferences.end();
  }
  Serial.println("gCurrentMonth: " + String(gCurrentMonth));
  Serial.println("gCurrentYear: " + String(gCurrentYear));
  Serial.println("gMode: " + String(gMode));
  


  // Auto update
  // -----------------------
  esp32FOTA.setManifestURL(manifest_url);

  // usage with lambda function:
  esp32FOTA.setProgressCb([](size_t progress, size_t size)
                          {
      if( progress == size || progress == 0 ) Serial.println();
      Serial.print("."); });

  CheckForUpdates();
}

void CheckForUpdates()
{
  bool updatedNeeded = esp32FOTA.execHTTPcheck();
  if (updatedNeeded)
  {
    Serial.println("!!! Update needed !!!! ");
    ShowGlyphUpdating();
    esp32FOTA.execOTA();
  }
  else
  {
    Serial.println("No update needed");
  }
}

// the loop function runs over and over again forever
void loop()
{
  EVERY_N_MINUTES_I(AUTO_UPDATE, 5)
  {
    CheckForUpdates();
  }

  // do some periodic updates
  EVERY_N_SECONDS(1)
  {
    flipTheStatusLED();
  }

  EVERY_N_MINUTES(10)
  {
    getCurrentTime();
  }

  switch (gMode)
  {
  case MODE_CALENDAR:
    modeCalendar();
    break;
  case MODE_BINARY_CLOCK:
    modeBinaryClock(timeClient.getEpochTime() + utcOffsetInSeconds);
    break;
  case MODE_EPOCH_CLOCK:
    modeEPOCHClock(timeClient.getEpochTime() + utcOffsetInSeconds);
    break;
  case MODE_BREATHING:
    modeBreathing();
    break;
  case MODE_FADE_POINTS:
    modeFadePoints();
    break;
  default:
    gMode = MODE_MIN;
    break;
  }

  // Check for user input to see if we need to change modes
  checkInputs();

  // Insert a delay to keep the framerate modest
  // FastLED.delay(1000 / FRAMES_PER_SECOND);
  FastLED.show();
}

void flipTheStatusLED()
{
  static bool statusLEDState = LOW;
  statusLEDState = !statusLEDState;
  digitalWrite(PIN_LED_STATUS, statusLEDState);
}

void checkInputs()
{
  const uint8_t BUTTON_DOWN_STATE = LOW;
  const CRGB BUTTON_DOWN_COLOR = CRGB::Gold;

  // Mode selectors
  if (digitalRead(PIN_MODE) == BUTTON_DOWN_STATE)
  {
    // Change the mode
    gMode++;
    if (gMode > MODE_MAX)
    {
      gMode = MODE_MIN;
    }

    switch (gMode)
    {
    case MODE_CALENDAR:
      ScrollText((String)gCurrentYear, COLOR_FONT, 50);
      ScrollText((String)MONTHS_SHORT[gCurrentMonth], COLOR_FONT, 50);
      break;
    case MODE_BINARY_CLOCK:
      ScrollText("T");
      break;
    case MODE_EPOCH_CLOCK:
      ScrollText("E");
      break;
    case MODE_BREATHING:
      ScrollText("B");
      break;
    case MODE_FADE_POINTS:
      ScrollText("F");
      break;
    default:
      // ScrollText("XX");
      gMode = MODE_CALENDAR;
      break;
    }

    Serial.println("Mode (gMode) changed to: " + (String)gMode);

    // Save settings
    Preferences preferences;
    preferences.begin("habit-tracker", false);
    preferences.putUChar("mode", gMode);
    preferences.end();
  }

  // Previous Month
  if (digitalRead(PIN_WIN1) == BUTTON_DOWN_STATE)
  {
    if (gCurrentMonth <= 1)
    {
      gCurrentMonth = 12;
      gCurrentYear -= 1;

      ScrollText((String)gCurrentYear, COLOR_FONT, 50);
    }
    else
    {
      gCurrentMonth -= 1;
    }

    Serial.println("gCurrentMonth: " + (String)gCurrentMonth + " (" + (String)MONTHS_SHORT[gCurrentMonth] + ") gCurrentYear: " + (String)gCurrentYear);
    Serial.println("GetEpochForDate: " + (String)GetEpochForDate(gCurrentYear, gCurrentMonth, 1));

    ScrollText((String)MONTHS_SHORT[gCurrentMonth], COLOR_FONT, 50);

    // Save settings
    Preferences preferences;
    preferences.begin("habit-tracker", false);
    preferences.putUChar("month", gCurrentMonth);
    preferences.putUShort("year", gCurrentYear);
    preferences.end();
  }
  // Next Month
  if (digitalRead(PIN_WIN2) == BUTTON_DOWN_STATE)
  {
    gCurrentMonth++;
    if (gCurrentMonth > 12)
    {
      gCurrentMonth = 1;
      gCurrentYear += 1;
      ScrollText((String)gCurrentYear, COLOR_FONT, 50);
    }

    Serial.println("gCurrentMonth: " + (String)gCurrentMonth + " (" + (String)MONTHS_SHORT[gCurrentMonth] + ") gCurrentYear: " + (String)gCurrentYear);
    Serial.println("GetEpochForDate: " + (String)GetEpochForDate(gCurrentYear, gCurrentMonth, 1));

    ScrollText((String)MONTHS_SHORT[gCurrentMonth], COLOR_FONT, 50);

    // Save settings
    Preferences preferences;
    preferences.begin("habit-tracker", false);
    preferences.putUChar("month", gCurrentMonth);
    preferences.putUShort("year", gCurrentYear);
    preferences.end();
  }

  // Check to see if the buttons have been pressed.
  // For weeks 1-6, set the entire horazonal row to the button down color
  // if (digitalRead(PIN_WEEK1) == BUTTON_DOWN_STATE)
  // {
  //   for (uint8_t offset = DAY1; offset <= DAY7; offset++)
  //   {
  //     leds[offset] = BUTTON_DOWN_COLOR;
  //   }
  // }
  // if (digitalRead(PIN_WEEK2) == BUTTON_DOWN_STATE)
  // {
  //   for (uint8_t offset = DAY8; offset <= DAY14; offset++)
  //   {
  //     leds[offset] = BUTTON_DOWN_COLOR;
  //   }
  // }
  // if (digitalRead(PIN_WEEK3) == BUTTON_DOWN_STATE)
  // {
  //   for (uint8_t offset = DAY15; offset <= DAY21; offset++)
  //   {
  //     leds[offset] = BUTTON_DOWN_COLOR;
  //   }
  // }
  // if (digitalRead(PIN_WEEK4) == BUTTON_DOWN_STATE)
  // {
  //   for (uint8_t offset = DAY22; offset <= DAY28; offset++)
  //   {
  //     leds[offset] = BUTTON_DOWN_COLOR;
  //   }
  // }
  // if (digitalRead(PIN_WEEK5) == BUTTON_DOWN_STATE)
  // {
  //   for (uint8_t offset = DAY29; offset <= DAY35; offset++)
  //   {
  //     leds[offset] = BUTTON_DOWN_COLOR;
  //   }
  // }
  // if (digitalRead(PIN_WEEK6) == BUTTON_DOWN_STATE)
  // {
  //   for (uint8_t offset = DAY36; offset <= DAY42; offset++)
  //   {
  //     leds[offset] = BUTTON_DOWN_COLOR;
  //   }
  // }

  // For days 1-7, use them as win conditions
  if (digitalRead(PIN_DAY1) == BUTTON_DOWN_STATE)
  {
    DatabaseSet(year(), month(), day(), 0, true);
    ScrollText("Win 1", COLOR_FONT, 50);
  }
  if (digitalRead(PIN_DAY2) == BUTTON_DOWN_STATE)
  {
    DatabaseSet(year(), month(), day(), 1, true);
    ScrollText("Win 2", COLOR_FONT, 50);
  }
  if (digitalRead(PIN_DAY3) == BUTTON_DOWN_STATE)
  {
    DatabaseSet(year(), month(), day(), 2, true);
    ScrollText("Win 3", COLOR_FONT, 50);
  }
  if (digitalRead(PIN_DAY4) == BUTTON_DOWN_STATE)
  {
    DatabaseSet(year(), month(), day(), 3, true);
    ScrollText("Win 4", COLOR_FONT, 50);
  }
  if (digitalRead(PIN_DAY5) == BUTTON_DOWN_STATE)
  {
    DatabaseSet(year(), month(), day(), 4, true);
    ScrollText("Win 5", COLOR_FONT, 50);
  }
  if (digitalRead(PIN_DAY6) == BUTTON_DOWN_STATE)
  {
    DatabaseSet(year(), month(), day(), 5, true);
    ScrollText("Win 6", COLOR_FONT, 50);
  }
  if (digitalRead(PIN_DAY7) == BUTTON_DOWN_STATE)
  {
    DatabaseSet(year(), month(), day(), 6, true);
    ScrollText("Win 7", COLOR_FONT, 50);
  }

  // if (digitalRead(PIN_PREV) == BUTTON_DOWN_STATE) { leds[28-1] = BUTTON_DOWN_COLOR; }
  // if (digitalRead(PIN_NEXT) == BUTTON_DOWN_STATE) { leds[35-1] = BUTTON_DOWN_COLOR; }
}

void getCurrentTime()
{
  // Serial.println(timeClient.getFormattedTime());

  // Calulate what was the day of the week at the start of this month (1st)
  // 0 = Sunday, 1 = Monday, 2 = Tuesday, 3 = Wednesday, 4 = Thursday, 5 = Friday, 6 = Saturday,
  Serial.print("Get Current Day of week (0=Sun): ");
  Serial.println(timeClient.getDay());

  Serial.print("Current Epoch Time: ");
  Serial.println(timeClient.getEpochTime());

  // digital clock display of the time
  Serial.print("TimeLib: ");
  Serial.print(hour());
  Serial.print(":");
  Serial.print(minute());
  Serial.print(":");
  Serial.print(second());
  Serial.print(" ");
  Serial.print(day());
  Serial.print(".");
  Serial.print(month());
  Serial.print(".");
  Serial.print(year());
  Serial.println();

  // Calulate the Epoch for the start of this month (1st)
  time_t startOfMonth = timeClient.getEpochTime() - (day() * 24 * 60 * 60);
  Serial.print("Start of month (epoch): ");
  Serial.println(startOfMonth);

  // figure out the day of the week for the start of this month
  int dayOfWeek = weekday(startOfMonth);
  Serial.print("Start of the month, day of week: ");
  Serial.println(dayOfWeek);

  // Figure out how many days are in this month (28, 29, 30, 31)
  int daysInMonth = monthDays(month(), year());
  Serial.print("Days in this month: ");
  Serial.println(daysInMonth);
}

time_t getNtpTime()
{
  timeClient.update();
  return timeClient.getEpochTime();
}

void modeCalendar()
{
  // Calulate the Epoch for the start of this month (1st)
  time_t startOfMonth = GetEpochForDate(gCurrentYear, gCurrentMonth, 1);
  // time_t startOfMonth = timeClient.getEpochTime() - (day() * 24 * 60 * 60);
  // Figure out the day of the week for the start of this month
  int dayOfWeek = weekday(startOfMonth) - 1;
  // Figure out how many days are in this month (28, 29, 30, 31)
  int daysInMonth = monthDays(gCurrentMonth, gCurrentYear);
  // 0 = Sunday, 1 = Monday, 2 = Tuesday, 3 = Wednesday, 4 = Thursday, 5 = Friday, 6 = Saturday,

  // Figure out if this month is in the future or not.
  bool isFuture = false;
  if (gCurrentYear > year())
  {
    isFuture = true;
  }
  else if (gCurrentYear == year())
  {
    if (gCurrentMonth > month())
    {
      isFuture = true;
    }
  }

  // Set all the LEDS to black.
  SetAllLEDs(COLOR_NOT_IN_MONTH);

  if (!isFuture)
  {
    // Fill in all the days with the data from the database
    for (int offset_pixel = dayOfWeek; offset_pixel < dayOfWeek + daysInMonth; offset_pixel++)
    {
      if (DatabaseGet(gCurrentYear, gCurrentMonth, offset_pixel - dayOfWeek + 1, 0))
      {
        leds[offset_pixel] = COLOR_SUCCESS; // Success
      }
      else
      {
        leds[offset_pixel] = COLOR_FAIL; // Failure
      }
    }
  }

  // If we are in the current year, and month.. Then show the future dates as COLOR_FUTURE
  if (gCurrentYear == year() && gCurrentMonth == month())
  {
    // fill the future days with gray color (no data)
    for (int offset_pixel = dayOfWeek + day(); offset_pixel < dayOfWeek + daysInMonth; offset_pixel++)
    {
      // divide the whole hue range across the number of pixels
      // and add the offset to the current pixel
      leds[offset_pixel] = COLOR_FUTURE;
    }

    // The current day of the month should fade in and out of the cursor color (gold)
    // and the background color showing what values have been set so far.
    leds[day() + dayOfWeek - 1] = breathBetweenToColors(COLOR_FAIL, COLOR_SUCCESS, 2.0);
  }
  else if (isFuture)
  {
    // If this month is in the future, then show the whole month as COLOR_FUTURE
    for (int offset_pixel = dayOfWeek; offset_pixel < dayOfWeek + daysInMonth; offset_pixel++)
    {
      leds[offset_pixel] = COLOR_FUTURE;
    }
  }
}

void modeBreathing()
{
  for (int offset_pixel = 0; offset_pixel < PIXELS_COUNT; offset_pixel++)
  {
    leds[offset_pixel] = breathBetweenToColors(CHSV(PIXELS_COUNT / 255 * offset_pixel, 255, 64), CHSV(255, 255, 255), offset_pixel % 7);
  }
}

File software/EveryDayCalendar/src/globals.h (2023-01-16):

/**
 * Globals
 * A list of global variables and constants used in the project
 * Multiple files will include this file
 *
 */

#include <Arduino.h> // Required for ESP32
#include "FastLED.h" // Required for CHSV


#ifndef __GLOBAL_H__
#define __GLOBAL_H__

// The build version is shown on the loading screen.
// the version is shown in the serial prompt and the web page.
const uint8_t BUILD_NUMBER = 8;

// HTTP
#define HTTP_PORT 80

// Pins
// ESP32 Pins
// https://docs.espressif.com/projects/esp-idf/en/latest/esp32/api-reference/peripherals/gpio.html
const int PIN_WEEK1 = 4;   // IO-4  or pin 26
const int PIN_WEEK2 = 16;  // IO-16 or pin 27
const int PIN_WEEK3 = 17;  // IO-17 or pin 28
const int PIN_WEEK4 = 5;   // IO-5  or pin 29
const int PIN_WEEK5 = 19;  // IO-19 or pin 31
const int PIN_WEEK6 = 18;  // IO-18 or pin 30
const int PIN_DAY1 = 23;   // IO-23 or pin 37
const int PIN_DAY2 = 22;   // IO-22 or pin 36
const int PIN_DAY3 = 21;   // IO-21 or pin 33
const int PIN_DAY4 = 15;   // IO-15 or pin 23
const int PIN_DAY5 = 12;   // IO-12 or pin 14
const int PIN_DAY6 = 14;   // IO-14 or pin 13
const int PIN_DAY7 = 27;   // IO-27 or pin 12, GPIO27, ADC2_CH7, TOUCH7, RTC_GPIO17, EMAC_RX_DV
const int PIN_WIN1 = 26;   // IO-26 or pin 11
const int PIN_WIN2 = 33;   // IO-33 or pin  9
const int PIN_MODE = 32;   // IO-32 or pin  8
const int PIN_NEXT = 34;   // IO-34 or pin  6, Shares pins with U0RXD (serial). If serial is active you can't use thse pins
const int PIN_PREV = 35;   // IO-35 or pin  7, Shares pins with U0TXD (serial)
const int PIN_ONEWIRE = 2; // IO-0 or pin 24

const int PIN_LED_CALENDAR = 25; // IO-25 or pin 10
const int PIN_LED_STATUS = 13;   // IO-13 or pin 16

// Helpful for debugging when identifiying
// The actual LED on the matrix that is being addressed
const uint8_t DAY1 = 0;
const uint8_t DAY2 = 1;
const uint8_t DAY3 = 2;
const uint8_t DAY4 = 3;
const uint8_t DAY5 = 4;
const uint8_t DAY6 = 5;
const uint8_t DAY7 = 6;
const uint8_t DAY8 = 7;
const uint8_t DAY9 = 8;
const uint8_t DAY10 = 9;
const uint8_t DAY11 = 10;
const uint8_t DAY12 = 11;
const uint8_t DAY13 = 12;
const uint8_t DAY14 = 13;
const uint8_t DAY15 = 14;
const uint8_t DAY16 = 15;
const uint8_t DAY17 = 16;
const uint8_t DAY18 = 17;
const uint8_t DAY19 = 18;
const uint8_t DAY20 = 19;
const uint8_t DAY21 = 20;
const uint8_t DAY22 = 21;
const uint8_t DAY23 = 22;
const uint8_t DAY24 = 23;
const uint8_t DAY25 = 24;
const uint8_t DAY26 = 25;
const uint8_t DAY27 = 26;
const uint8_t DAY28 = 27;
const uint8_t DAY29 = 28;
const uint8_t DAY30 = 29;
const uint8_t DAY31 = 30;
const uint8_t DAY32 = 31;
const uint8_t DAY33 = 32;
const uint8_t DAY34 = 33;
const uint8_t DAY35 = 34;
const uint8_t DAY36 = 35;
const uint8_t DAY37 = 36;
const uint8_t DAY38 = 37;
const uint8_t DAY39 = 38;
const uint8_t DAY40 = 39;
const uint8_t DAY41 = 40;
const uint8_t DAY42 = 41;

// Modes
const uint8_t MODE_CALENDAR = 0;
const uint8_t MODE_BINARY_CLOCK = 1;
const uint8_t MODE_EPOCH_CLOCK = 2;
const uint8_t MODE_BREATHING = 3;
const uint8_t MODE_FADE_POINTS = 4;

const uint8_t MODE_START = MODE_FADE_POINTS;
const uint8_t MODE_MIN = MODE_CALENDAR;
const uint8_t MODE_MAX = MODE_FADE_POINTS;

// LED colors
// https://github.com/FastLED/FastLED/wiki/Pixel-reference
const CHSV COLOR_OFF = CHSV(0, 0, 0);          // Black
const CHSV COLOR_SUCCESS = CHSV(96, 255, 200); // Green
const CHSV COLOR_FAIL = CHSV(0, 255, 128);     // RED
const CHSV COLOR_FUTURE = CHSV(128, 255, 128); // Aqua
const CHSV COLOR_NOT_IN_MONTH = COLOR_OFF;     // Black
const CRGB COLOR_CURSOR = CRGB::Gold;
const CHSV COLOR_FONT = COLOR_SUCCESS;

const uint8_t LED_MATRIX_WIDTH = 7;
const uint8_t LED_MATRIX_HEIGHT = 6;

#define DAYS_IN_YEAR 365

const int timeZone = -8; // Pacific Standard Time (USA)
const long utcOffsetInSeconds = timeZone * 60 * 60;

static const char *MONTHS_SHORT[] = {"XXX", "Jan", "Feb", "Mar", "Apr", "May", "Jun", "Jul", "Aug", "Sep", "Oct", "Nov", "Dec"};

// 0 = Sunday, 1 = Monday, 2 = Tuesday, 3 = Wednesday, 4 = Thursday, 5 = Friday, 6 = Saturday,
static const char *DAY_SHORT[] = {"Sun", "Mon", "Tue", "Wen", "Thu", "Fri", "Sat"};

// Settings
// ------------------------------------------------------------
const uint8_t PIXELS_COUNT = LED_MATRIX_WIDTH * LED_MATRIX_HEIGHT; // 7x6
const uint8_t LED_BRIGHTNESS = 64;                                 // 0 DARK - 255 BRIGHT
const ulong FRAMES_PER_SECOND = 120;
const uint32_t BAUD_RATE = 115200;

// Globals
// ------------------------------------------------------------
// NeoPixel
extern CRGB leds[PIXELS_COUNT];


static uint8_t gMode;
static uint16_t gCurrentYear;
static uint8_t gCurrentMonth;

#endif // __GLOBAL_H__

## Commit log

2022-11-28 WIP PCB Schematic
    [EveryDayCalendarSingleMonth.kicad_pcb, EveryDayCalendarSingleMonth.kicad_sch, rp2040_cpu.kicad_sch]
2022-12-04 Move from RP2040 to ESP32, schematic mostly complete
    [EveryDayCalendarSingleMonth.kicad_sch, rp2040_cpu.kicad_sch]
2022-12-05 Schematic complete, pcb outline in place
    [EveryDayCalendarSingleMonth.csv, EveryDayCalendarSingleMonth.kicad_pcb, EveryDayCalendarSingleMonth.kicad_sch]
2022-12-05 First step in PCB layout, getting everything sorted into their general locations
    [EveryDayCalendarSingleMonth.kicad_pcb]
2022-12-05 Working on getting all the traces done
    [EveryDayCalendarSingleMonth.kicad_pcb, EveryDayCalendarSingleMonth.kicad_sch]
2022-12-06 added GND base
    [EveryDayCalendarSingleMonth.kicad_pcb, EveryDayCalendarSingleMonth.kicad_sch]
2022-12-06 Added 3d part for pushbuttons
    [EveryDayCalendarSingleMonth.kicad_pcb, EveryDayCalendarSingleMonth.kicad_sch]
2022-12-06 Zero errors or warnings.
    [EveryDayCalendarSingleMonth.kicad_pcb, EveryDayCalendarSingleMonth.kicad_sch]
2022-12-06 Updated silkscreen
    [EveryDayCalendarSingleMonth.kicad_pcb, EveryDayCalendarSingleMonth.kicad_sch]
2022-12-06 Updated the schematic from PCB layout with updated silkscreen
    [EveryDayCalendarSingleMonth.kicad_pcb, EveryDayCalendarSingleMonth.kicad_sch]
2022-12-06 Fussing with the tracks, no real change
    [EveryDayCalendarSingleMonth.kicad_pcb, EveryDayCalendarSingleMonth.kicad_sch]
2022-12-07 Keep optimizing the tracks
    [EveryDayCalendarSingleMonth.kicad_pcb]
2022-12-07 Added gerber files
    [EveryDayCalendarSingleMonth-B_Cu.gbl, EveryDayCalendarSingleMonth-B_Mask.gbs, EveryDayCalendarSingleMonth-B_Paste.gbp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]
2022-12-07 added BOM
    [EveryDayCalendarSingleMonth.csv]
2022-12-11 As submitted to jlcpcb on Dec 10, 2022
    [EveryDayCalendarSingleMonth-B_Cu.gbl, EveryDayCalendarSingleMonth-B_Mask.gbs, EveryDayCalendarSingleMonth-B_Paste.gbp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]
2022-12-12 Restored from backups after bad merge
    [EveryDayCalendarSingleMonth-B_Cu.gbl, EveryDayCalendarSingleMonth-B_Mask.gbs, EveryDayCalendarSingleMonth-B_Paste.gbp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]
2022-12-12 As submitted to JLPCB on 11-Dec-2022
    [EveryDayCalendarSingleMonth.kicad_pcb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]
2022-12-12 Moved the LEDs slightly and resubmitted to JLPCB
    [EveryDayCalendarSingleMonth-B_Cu.gbl, EveryDayCalendarSingleMonth-B_Mask.gbs, EveryDayCalendarSingleMonth-B_Paste.gbp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]
2022-12-29 Next and Prev month buttons
2023-01-04 Moved modes to their own files, Added a fades pixel animation, Added reset wifi command
    [animation.cpp, globals.h]
2023-01-09 Added laser cut files for the top plate, separator, and back plate
    [12MonthCalendar_backing.dxf, 1month_bottom_plate.dxf, 1month_top_plate.dxf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]
2023-01-12 Testing esp32FOTA version 0.0.5
2023-01-16 version 6
    ## 2023-Jan-08 (build 6)
    - Save the month, year, and mode to eeprom on change
    - Randomized seed on startup based on wifi noise
    ## 2023-Jan-08 (build 3-5)
    - Added ability to update via Github
    [globals.h, main.cpp]
2023-01-16 If year is corrupted then reset year to 2023 (build 7)
    [main.cpp]
2023-01-16 Fixed issue where mode was not being saved between power cycles (build 8)
    ## 2023-Jan-08 (build 8)
    - Fixed issue where mode was not being saved between power cycles
    [animation.cpp, globals.h, main.cpp]
